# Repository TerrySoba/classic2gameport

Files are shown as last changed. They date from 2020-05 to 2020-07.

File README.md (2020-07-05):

Classic2Gameport
================

About
-----
Classic2Gameport is an adapter that allows to connect up to two [Nintendo Wii Classic Controllers](https://en.wikipedia.org/wiki/Classic_Controller) to [PC Gameports](https://en.wikipedia.org/wiki/Game_port).
The adapter acts like a Gravis Gamepad.

Supported Devices
-----------------

The following Nintendo controllers are supported:
 * Classic Controller
 * Classic Controler Pro
 * SNES Mini Controller

The PC needs to have a Gameport to use this adapter.

Adapter Modes
-------------

| Mode | Combination | Description |
|---|---|--|
| Normal Mode | SELECT + DOWN | Button B -> 1<br>Button Y -> 2<br>Button A -> 3<br>Button X -> 4 |
| Two Player Mode | (connect two controllers) | Button B1 -> 1<br>Button Y1 -> 2<br>Button B2 -> 3<br>Button Y2 -> 4<br>
| Jump'n'Run Mode | SELECT + UP | Button Y -> 1<br>Button A -> 2<br>Button B -> Up |

Building Instructions
---------------------

Here are some images of the assembled adapter:

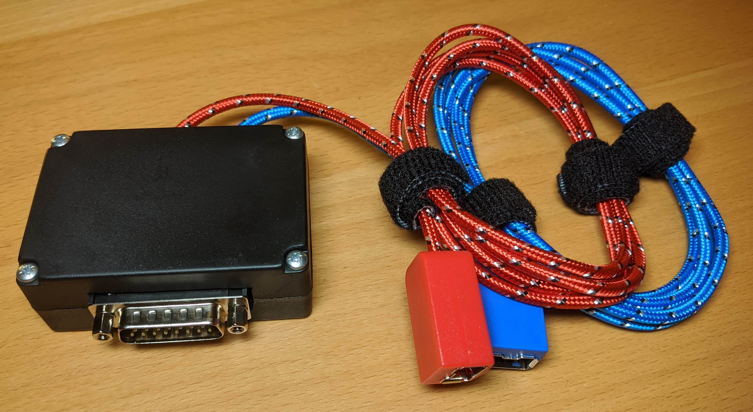
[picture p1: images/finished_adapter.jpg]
pcb v4 front The finished adapter

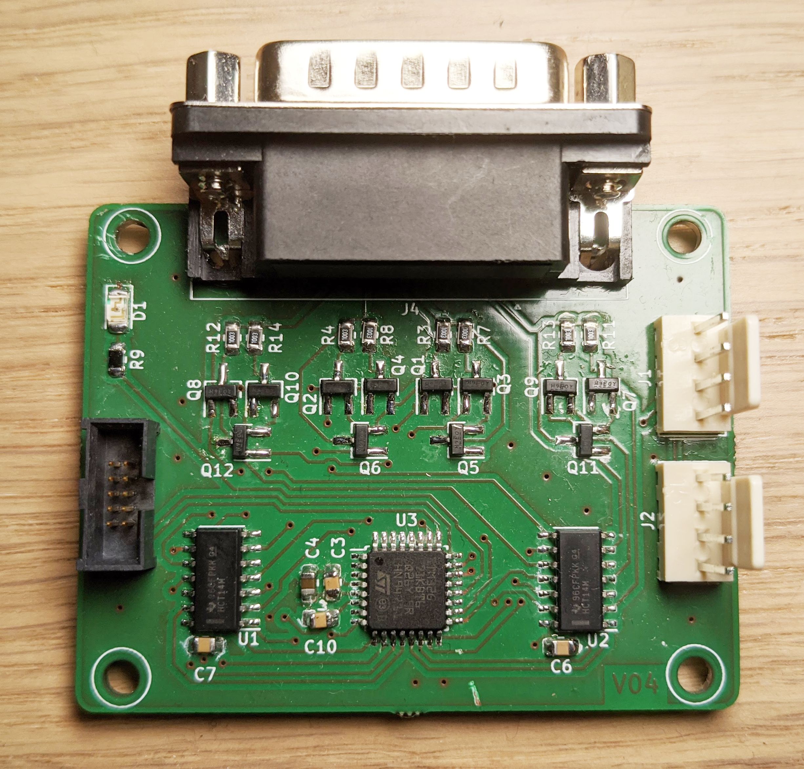
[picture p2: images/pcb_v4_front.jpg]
pcb v4 front PCB Version 4 Front

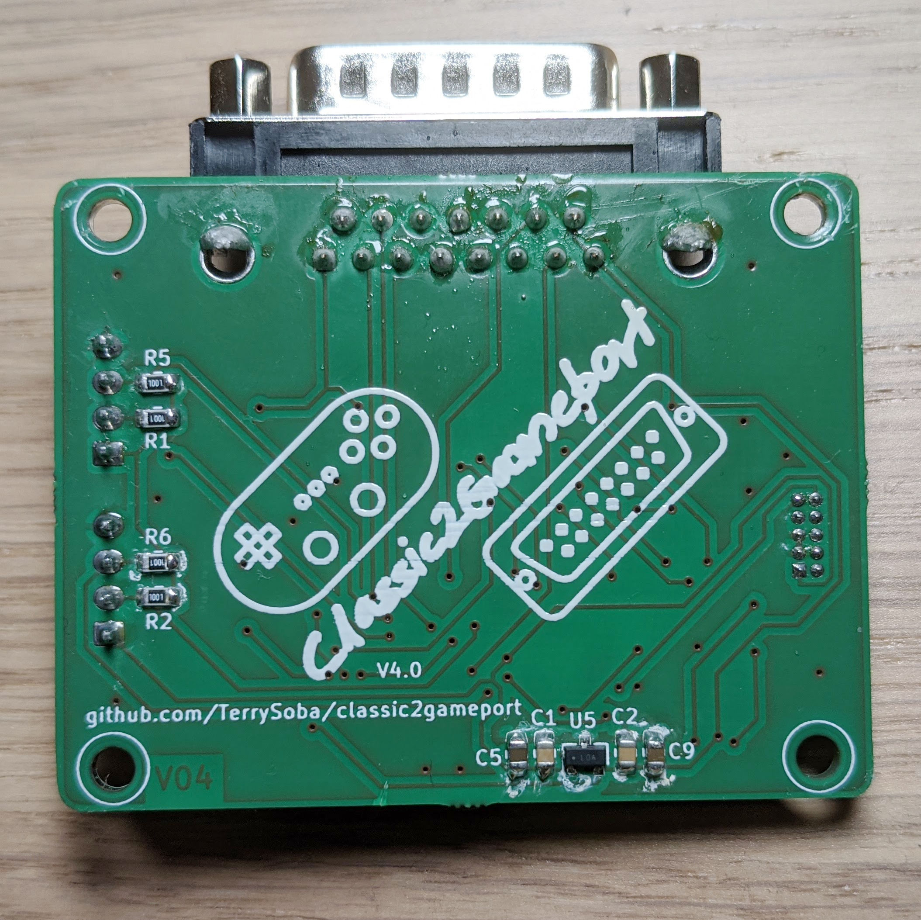
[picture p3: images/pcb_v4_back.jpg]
pcb v4 back PCB Version 4 Back


The Kicad files of the PCB can be found in the pcb directory of the repository.

The firmware for the ST STM32G071KxT microcontroller can be found in the firmware directory.

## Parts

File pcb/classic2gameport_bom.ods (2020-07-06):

Id | Designator | Package | Quantity | Designation | Supplier and ref | Digikey
1 | REF** | G026 | 1 | G026 | Reichelt: GEH KS 28
2 | U3 | LQFP-32_7x7mm_P0.8mm | 1 | STM32G071KxT | Farnell: 2980897 | 497-18355-ND
3 | C10,C7,C6,C3,C2,C1 | C_0805_2012Metric_Pad1.15x1.40mm_HandSolder | 6 | 100nF | Farnell: 2320839 | 399-8000-1-ND
4 | C9,C5 | C_0805_2012Metric_Pad1.15x1.40mm_HandSolder | 2 | 4.7µF | Farnell: 2906811 | 399-C0805C475K3RACAUTOCT-ND
5 | U5 | SOT-23 | 1 | LM3480-3.3 | Farnell: 3122097 | LM3480IM3X-3.3/NOPBCT-ND
6 | U2,U1 | SOIC-14_3.9x8.7mm_P1.27mm | 2 | 74HC14 | Farnell: 3120226 | 296-14548-1-ND
7 | R14,R13,R12,R11,R8,R7,R4,R3 | R_0805_2012Metric_Pad1.15x1.40mm_HandSolder | 8 | 100kR | Farnell: 2447551 | 311-100KCRCT-ND
8 | R9 | R_0805_2012Metric_Pad1.15x1.40mm_HandSolder | 1 | 470R | Farnell: 2447662 | A129745CT-ND
9 | R6,R5,R2,R1 | R_0805_2012Metric_Pad1.15x1.40mm_HandSolder | 4 | 1kR | Farnell: 2447587 | 311-1.0KARCT-ND
10 | Q12,Q11,Q10,Q9,Q8,Q7,Q6,Q5,Q4,Q3,Q2,Q1 | SOT-23_Handsoldering | 12 | Q_PMOS_GSD | Farnell: 9103511 | IRLML5203TRPBFCT-ND
11 | J4 | DSUB-15_Male_Horizontal_P2.77x2.84mm_EdgePinOffset4.94mm_Housed_MountingHolesOffset7.48mm | 1 | DB15_Male | Reichelt: RND 205-00772 | 732-618015211721-ND
12 | J3 | PinHeader_2x05_P1.27mm_Vertical | 1 | Conn_02x05_Odd_Even | Farnell: 2308450 | 1175-1733-ND
13 | J2,J1 | Molex_KK-254_AE-6410-04A_1x04_P2.54mm_Vertical | 2 | Conn_01x04 | Reichelt: RND 205-00664 + Reichelt: RND 205-00696 + Reichelt: RND 205-00673 | WM4202-ND
14 | D1 | LED_1206_3216Metric | 1 | LED | Reichelt: KBT KP-3216SURC | 754-APTL3216SURCK-01CT-ND
15 | C4 | C_0805_2012Metric_Pad1.15x1.40mm_HandSolder | 1 | 1µF | Farnell: 1637035 | 399-8004-1-ND

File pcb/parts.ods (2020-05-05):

Designation | Part Name | Package | Farnell Number | Value
U3 | PCA9306D,118 | SO8 | 2820288
U2 | ATMEGA8A-PU | DIP-28 | 1748534
U1 | LM3480-3.3 | SOT-23 | 3122097
J1 |  | DSUB-15 | 1099290
Y1 |  | HC-49 | 1611761 | 16MHz
Q1..Q8 | IRLML5203TRPBF | SOT-23 | 9103511
 | LED blue | 1206 | 2846600

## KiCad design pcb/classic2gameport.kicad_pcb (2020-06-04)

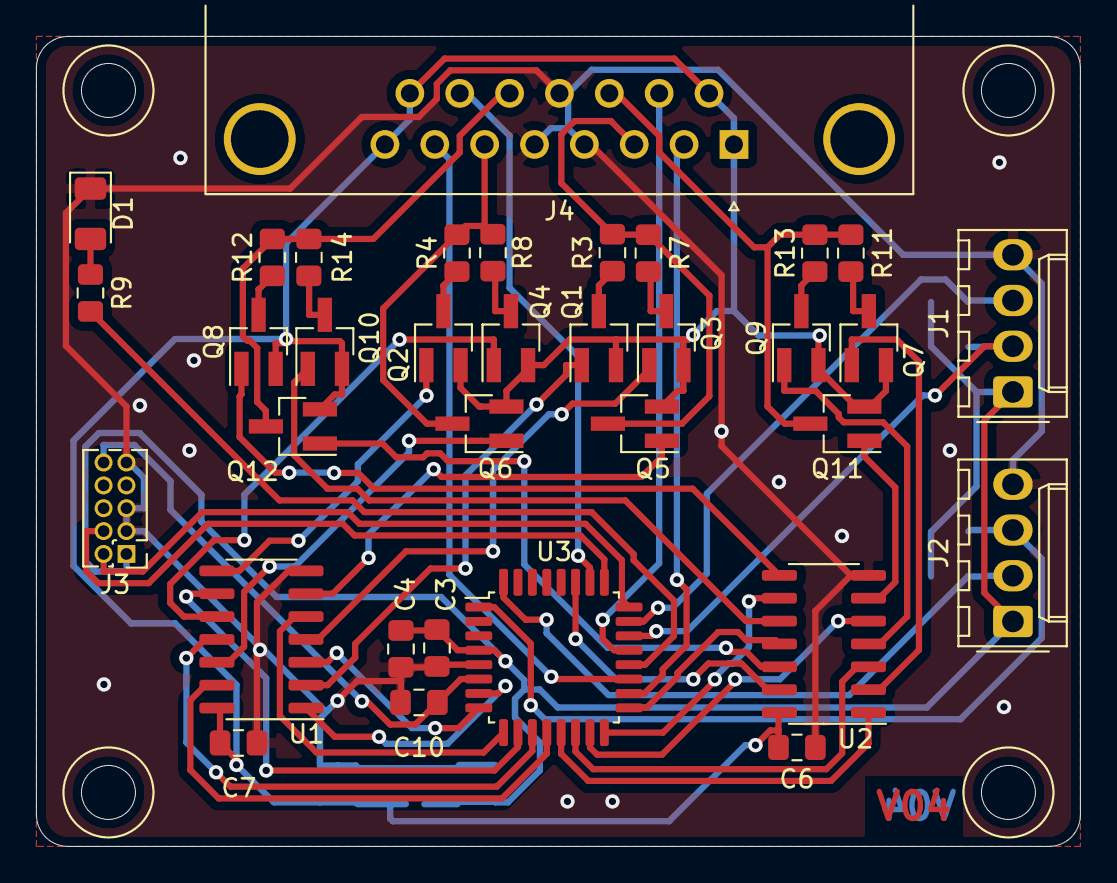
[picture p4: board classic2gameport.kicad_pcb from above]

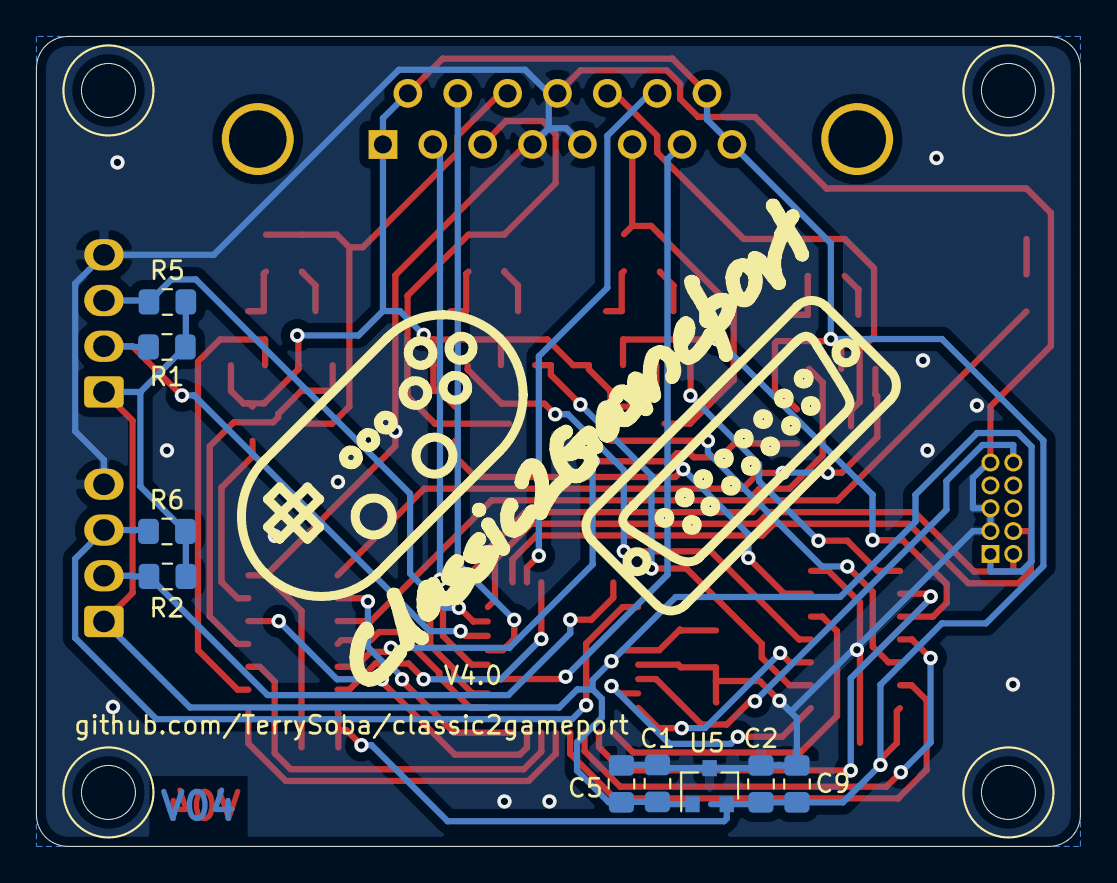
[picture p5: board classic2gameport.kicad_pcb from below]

Board: 2 copper layers, 58.0 x 45.0 mm, 43 parts (9 on the bottom side), 52 nets.

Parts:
C1, C2, C3, C6, C7, C10: 100nF; C_0805_2012Metric_Pad1.15x1.40mm_HandSolder
C4: 1µF; C_0805_2012Metric_Pad1.15x1.40mm_HandSolder
C5, C9: 4.7µF; C_0805_2012Metric_Pad1.15x1.40mm_HandSolder
D1: LED; LED_1206_3216Metric
J1, J2: Conn_01x04; Molex_KK-254_AE-6410-04A_1x04_P2.54mm_Vertical
J3: Conn_02x05_Odd_Even; PinHeader_2x05_P1.27mm_Vertical
J4: DB15_Male; DSUB-15_Male_Horizontal_P2.77x2.84mm_EdgePinOffset4.94mm_Ho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
Q1, Q2, Q3, Q4, Q5, Q6, Q7, Q8, Q9, Q10, Q11, Q12: Q_PMOS_GSD; SOT-23_Handsoldering
R1, R2, R5, R6: 1kR; R_0805_2012Metric_Pad1.15x1.40mm_HandSolder
R3, R4, R7, R8, R11, R12, R13, R14: 100kR; R_0805_2012Metric_Pad1.15x1.40mm_HandSolder
R9: 470R; R_0805_2012Metric_Pad1.15x1.40mm_HandSolder
U1, U2: 74HC14; SOIC-14_3.9x8.7mm_P1.27mm
U3: STM32G071KxT; LQFP-32_7x7mm_P0.8mm
U5: LM3480-3.3; SOT-23

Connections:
3.3V: C1.1, C3.1, C4.1, C5.1, J1.1, J2.1, J3.1, R1.1, R2.1, R5.1, R6.1, U3.4, U5.1
5V: C2.1, C6.1, C7.1, C9.1, J4.1, J4.8, J4.9, J4.15, Q1.2, Q2.2, Q3.2, Q4.2, Q5.2, Q6.2, Q7.2, Q8.2, Q9.2, Q10.2, Q11.2, Q12.2, U1.14, U2.14, U5.2
BUTTON1: J4.2, U3.18
BUTTON2: J4.7, U3.19
BUTTON3: J4.10, U3.21
BUTTON4: J4.14, U3.26
GND: C1.2, C2.2, C3.2, C4.2, C5.2, C6.2, C7.2, C9.2, C10.2, D1.1, J1.4, J2.4, J3.3, J3.5, J3.9, J4.4, J4.5, J4.12, U1.7, U2.7, U3.5, U5.3
JS1_X1: U1.1, U3.7
JS1_X2: U1.3, U3.8
JS1_X3: U1.5, U3.9
JS1_X_AXIS: J4.3, Q5.3, R3.2, R7.2
JS1_Y1: U1.9, U3.10
JS1_Y2: U1.11, U3.11
JS1_Y3: U1.13, U3.12
JS1_Y_AXIS: J4.6, Q6.3, R4.2, R8.2
JS2_X1: U2.1, U3.13
JS2_X2: U2.3, U3.14
JS2_X3: U2.5, U3.15
JS2_X_AXIS: J4.11, Q11.3, R11.2, R13.2
JS2_Y1: U2.9, U3.16
JS2_Y2: U2.11, U3.17
JS2_Y3: U2.13, U3.27
JS2_Y_AXIS: J4.13, Q12.3, R12.2, R14.2
NRST: C10.1, J3.10, U3.6
unnamed: D1.2, R9.2
unnamed: Q1.1, U1.2
unnamed: Q1.3, R3.1
unnamed: Q2.1, U1.8
unnamed: Q2.3, R4.1
unnamed: Q3.1, U1.4
unnamed: Q3.3, R7.1
unnamed: Q4.1, U1.10
unnamed: Q4.3, R8.1
unnamed: Q5.1, U1.6
unnamed: Q6.1, U1.12
unnamed: Q7.1, U2.2
unnamed: Q7.3, R11.1
unnamed: Q8.1, U2.8
unnamed: Q8.3, R12.1
unnamed: Q9.1, U2.4
unnamed: Q9.3, R13.1
unnamed: Q10.1, U2.10
unnamed: Q10.3, R14.1
unnamed: Q11.1, U2.6
unnamed: Q12.1, U2.12
unnamed: R9.1, U3.20
SCL: J2.2, R2.2, U3.32
SCL2: J1.2, R1.2, U3.22
SDA: J2.3, R6.2, U3.1
SDA2: J1.3, R5.2, U3.23
SWCLK: J3.4, U3.25
SWDIO: J3.2, U3.24

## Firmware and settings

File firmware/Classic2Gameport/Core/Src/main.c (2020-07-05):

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

/* Includes ------------------------------------------------------------------*/
#include "main.h"

/* USER CODE BEGIN Includes */
#include "classic_controller.h"
#include "gameport.h"
#include "button_mapper.h"
/* USER CODE END Includes */

I2C_HandleTypeDef hi2c1;
I2C_HandleTypeDef hi2c2;

void SystemClock_Config(void);
static void MX_GPIO_Init(void);
static void MX_I2C2_Init(void);
static void MX_I2C1_Init(void);
/* USER CODE BEGIN 0 */

ButtonMap buttonMapPort1[] =
{
    {MAP_TYPE_AXIS, true, 0, 0,                       AXIS_X2, POSITION_DISCONNECTED, 0},
    {MAP_TYPE_AXIS, true, 0, 0,                       AXIS_Y2, POSITION_DISCONNECTED, 0},
    {MAP_TYPE_AXIS, false, 1 << CLASSIC_BTN_left,  0, AXIS_X1, POSITION_MIN, 0},
    {MAP_TYPE_AXIS, false, 1 << CLASSIC_BTN_right, 0, AXIS_X1, POSITION_MAX, 0},
    {MAP_TYPE_AXIS, false, 1 << CLASSIC_BTN_up,    0, AXIS_Y1, POSITION_MIN, 0},
    {MAP_TYPE_AXIS, false, 1 << CLASSIC_BTN_down,  0, AXIS_Y1, POSITION_MAX, 0},
    {MAP_TYPE_BUTTON, false, 1 << CLASSIC_BTN_b,     0, 0, 0,                0},
    {MAP_TYPE_BUTTON, false, 1 << CLASSIC_BTN_y,     0, 0, 0,                1},
	{MAP_TYPE_BUTTON, false, 1 << CLASSIC_BTN_select,0, 0, 0,                1},
    {MAP_TYPE_BUTTON, false, 1 << CLASSIC_BTN_a,     0, 0, 0,                2},
    {MAP_TYPE_BUTTON, false, 1 << CLASSIC_BTN_x,     0, 0, 0,                3},
	{MAP_TYPE_BUTTON, false, 1 << CLASSIC_BTN_start, 0, 0, 0,                3},
    {MAP_TYPE_END,    false, 0                 ,     0, 0, 0,                0},
};

ButtonMap buttonMapPort1Jnr[] =
{
    {MAP_TYPE_AXIS, true, 0, 0,                       AXIS_X2, POSITION_DISCONNECTED, 0},
    {MAP_TYPE_AXIS, true, 0, 0,                       AXIS_Y2, POSITION_DISCONNECTED, 0},
    {MAP_TYPE_AXIS, false, 1 << CLASSIC_BTN_left,  0, AXIS_X1, POSITION_MIN, 0},
    {MAP_TYPE_AXIS, false, 1 << CLASSIC_BTN_right, 0, AXIS_X1, POSITION_MAX, 0},
    {MAP_TYPE_AXIS, false, 1 << CLASSIC_BTN_up,    0, AXIS_Y1, POSITION_MIN, 0},
    {MAP_TYPE_AXIS, false, 1 << CLASSIC_BTN_b,     0, AXIS_Y1, POSITION_MIN, 0}, // b is mapped to up
    {MAP_TYPE_AXIS, false, 1 << CLASSIC_BTN_down,  0, AXIS_Y1, POSITION_MAX, 0},
    {MAP_TYPE_BUTTON, false, 1 << CLASSIC_BTN_y,     0, 0, 0,                0},
    {MAP_TYPE_BUTTON, false, 1 << CLASSIC_BTN_a,     0, 0, 0,                1},
    {MAP_TYPE_END,    false, 0                 ,     0, 0, 0,                0},
};

ButtonMap buttonMapPort2[] =
{
    {MAP_TYPE_AXIS, true, 0, 0,                       AXIS_X2, POSITION_DISCONNECTED, 0},
    {MAP_TYPE_AXIS, true, 0, 0,                       AXIS_Y2, POSITION_DISCONNECTED, 0},
    {MAP_TYPE_AXIS, false, 0, 1 << CLASSIC_BTN_left,  AXIS_X1, POSITION_MIN, 0},
    {MAP_TYPE_AXIS, false, 0, 1 << CLASSIC_BTN_right, AXIS_X1, POSITION_MAX, 0},
    {MAP_TYPE_AXIS, false, 0, 1 << CLASSIC_BTN_up,    AXIS_Y1, POSITION_MIN, 0},
    {MAP_TYPE_AXIS, false, 0, 1 << CLASSIC_BTN_down,  AXIS_Y1, POSITION_MAX, 0},
    {MAP_TYPE_BUTTON, false, 0, 1 << CLASSIC_BTN_b,     0, 0,                0},
    {MAP_TYPE_BUTTON, false, 0, 1 << CLASSIC_BTN_y,     0, 0,                1},
	{MAP_TYPE_BUTTON, false, 0, 1 << CLASSIC_BTN_select,0, 0,                1},
    {MAP_TYPE_BUTTON, false, 0, 1 << CLASSIC_BTN_a,     0, 0,                2},
    {MAP_TYPE_BUTTON, false, 0, 1 << CLASSIC_BTN_x,     0, 0,                3},
	{MAP_TYPE_BUTTON, false, 0, 1 << CLASSIC_BTN_start, 0, 0,                3},
    {MAP_TYPE_END,  false, 0,                  0,       0, 0,                0},
};

ButtonMap buttonMapPort2Jnr[] =
{
    {MAP_TYPE_AXIS, true, 0, 0,                       AXIS_X2, POSITION_DISCONNECTED, 0},
    {MAP_TYPE_AXIS, true, 0, 0,                       AXIS_Y2, POSITION_DISCONNECTED, 0},
    {MAP_TYPE_AXIS, false, 0, 1 << CLASSIC_BTN_left,  AXIS_X1, POSITION_MIN, 0},
    {MAP_TYPE_AXIS, false, 0, 1 << CLASSIC_BTN_right, AXIS_X1, POSITION_MAX, 0},
    {MAP_TYPE_AXIS, false, 0, 1 << CLASSIC_BTN_up,    AXIS_Y1, POSITION_MIN, 0},
    {MAP_TYPE_AXIS, false, 0, 1 << CLASSIC_BTN_b,     AXIS_Y1, POSITION_MIN, 0}, // b is mapped to up
    {MAP_TYPE_AXIS, false, 0, 1 << CLASSIC_BTN_down,  AXIS_Y1, POSITION_MAX, 0},
    {MAP_TYPE_BUTTON, false, 0, 1 << CLASSIC_BTN_y,     0, 0,                0},
    {MAP_TYPE_BUTTON, false, 0, 1 << CLASSIC_BTN_a,     0, 0,                1},
    {MAP_TYPE_END,  false, 0,                  0,       0, 0,                0},
};

ButtonMap buttonMapBoth[] =
{
    {MAP_TYPE_AXIS, false, 1 << CLASSIC_BTN_left,  0, AXIS_X1, POSITION_MIN, 0},
    {MAP_TYPE_AXIS, false, 1 << CLASSIC_BTN_right, 0, AXIS_X1, POSITION_MAX, 0},
    {MAP_TYPE_AXIS, false, 1 << CLASSIC_BTN_up,    0, AXIS_Y1, POSITION_MIN, 0},
    {MAP_TYPE_AXIS, false, 1 << CLASSIC_BTN_down,  0, AXIS_Y1, POSITION_MAX, 0},
    {MAP_TYPE_AXIS, false, 0, 1 << CLASSIC_BTN_left,  AXIS_X2, POSITION_MIN, 0},
    {MAP_TYPE_AXIS, false, 0, 1 << CLASSIC_BTN_right, AXIS_X2, POSITION_MAX, 0},
    {MAP_TYPE_AXIS, false, 0, 1 << CLASSIC_BTN_up,    AXIS_Y2, POSITION_MIN, 0},
    {MAP_TYPE_AXIS, false, 0, 1 << CLASSIC_BTN_down,  AXIS_Y2, POSITION_MAX, 0},
    {MAP_TYPE_BUTTON, false, 1 << CLASSIC_BTN_b,    0,  0, 0,                0},
    {MAP_TYPE_BUTTON, false, 1 << CLASSIC_BTN_y,    0,  0, 0,                1},
    {MAP_TYPE_BUTTON, false, 0, 1 << CLASSIC_BTN_b,     0, 0,                2},
    {MAP_TYPE_BUTTON, false, 0, 1 << CLASSIC_BTN_y,     0, 0,                3},
    {MAP_TYPE_END, false, 0,                  0,        0, 0,                0},
};

ButtonMap buttonMapBothJnr[] =
{
    {MAP_TYPE_AXIS, false, 1 << CLASSIC_BTN_left,  0, AXIS_X1, POSITION_MIN, 0},
    {MAP_TYPE_AXIS, false, 1 << CLASSIC_BTN_right, 0, AXIS_X1, POSITION_MAX, 0},
    {MAP_TYPE_AXIS, false, 1 << CLASSIC_BTN_up,    0, AXIS_Y1, POSITION_MIN, 0},
    {MAP_TYPE_AXIS, false, 1 << CLASSIC_BTN_b,     0, AXIS_Y1, POSITION_MIN, 0}, // b is also mapped to up
    {MAP_TYPE_AXIS, false, 1 << CLASSIC_BTN_down,  0, AXIS_Y1, POSITION_MAX, 0},
    {MAP_TYPE_AXIS, false, 0, 1 << CLASSIC_BTN_left,  AXIS_X2, POSITION_MIN, 0},
    {MAP_TYPE_AXIS, false, 0, 1 << CLASSIC_BTN_right, AXIS_X2, POSITION_MAX, 0},
    {MAP_TYPE_AXIS, false, 0, 1 << CLASSIC_BTN_up,    AXIS_Y2, POSITION_MIN, 0},
    {MAP_TYPE_AXIS, false, 0, 1 << CLASSIC_BTN_b,     AXIS_Y2, POSITION_MIN, 0}, // b is also mapped to up
    {MAP_TYPE_AXIS, false, 0, 1 << CLASSIC_BTN_down,  AXIS_Y2, POSITION_MAX, 0},
    {MAP_TYPE_BUTTON, false, 1 << CLASSIC_BTN_y,    0,  0, 0,                0},
    {MAP_TYPE_BUTTON, false, 1 << CLASSIC_BTN_a,    0,  0, 0,                1},
    {MAP_TYPE_BUTTON, false, 0, 1 << CLASSIC_BTN_y,     0, 0,                2},
    {MAP_TYPE_BUTTON, false, 0, 1 << CLASSIC_BTN_a,     0, 0,                3},
    {MAP_TYPE_END, false, 0,                  0,        0, 0,                0},
};

static const uint16_t normalModeButtons = ~(1 << CLASSIC_BTN_select | 1 << CLASSIC_BTN_down);
static const uint16_t jumpAndRunModeButtons = ~(1 << CLASSIC_BTN_select | 1 << CLASSIC_BTN_up);

bool jumpAndRunMode = false;

/* USER CODE END 0 */

/**
  * @brief  The application entry point.
  * @retval int
  */
int main(void)
{
  /* MCU Configuration--------------------------------------------------------*/

  /* Reset of all peripherals, Initializes the Flash interface and the Systick. */
  HAL_Init();

  /* Configure the system clock */
  SystemClock_Config();

  /* Initialize all configured peripherals */
  MX_GPIO_Init();
  MX_I2C2_Init();
  MX_I2C1_Init();
  /* USER CODE BEGIN 2 */
soft_reset:

  HAL_Delay(100);
  initializeClassicController(&hi2c1);
  initializeClassicController(&hi2c2);
  HAL_Delay(100);

  /* USER CODE END 2 */

  /* Infinite loop */
  /* USER CODE BEGIN WHILE */

  uint16_t classicControllerButtons1 = 0;
  uint16_t classicControllerButtons2 = 0;

  while (1)
  {
    bool pad1Ready = readClassicControllerData(&hi2c1, &classicControllerButtons1);
    bool pad2Ready = readClassicControllerData(&hi2c2, &classicControllerButtons2);


    if (!pad1Ready && !pad2Ready)
    {
      goto soft_reset;
    }

    if (jumpAndRunModeButtons == classicControllerButtons1 || jumpAndRunModeButtons == classicControllerButtons2)
    {
      jumpAndRunMode = true;
    }

    if (normalModeButtons == classicControllerButtons1 || normalModeButtons == classicControllerButtons2)
    {
      jumpAndRunMode = false;
    }



    ButtonMap* map;


    if (pad1Ready && pad2Ready)
    {
      map = jumpAndRunMode?buttonMapBothJnr:buttonMapBoth;
    }
    else if (pad1Ready)
    {
      map = jumpAndRunMode?buttonMapPort1Jnr:buttonMapPort1;
    }
    else
    {
      map = jumpAndRunMode?buttonMapPort2Jnr:buttonMapPort2;
    }
  

    GameportState gameportState = mapButtons(classicControllerButtons1, classicControllerButtons2, map);
    setGameport(&gameportState);

    /* USER CODE END WHILE */

    /* USER CODE BEGIN 3 */
  }
  /* USER CODE END 3 */
}

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


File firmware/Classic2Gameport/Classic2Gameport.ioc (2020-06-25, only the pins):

Mcu.UserName=STM32G071KBTx
PA0.Signal=GPIO_Output
PA1.Signal=GPIO_Output
PA10.Signal=GPIO_Input
PA15.Signal=GPIO_Input
PA2.Signal=GPIO_Output
PA3.Signal=GPIO_Output
PA4.Signal=GPIO_Output
PA5.Signal=GPIO_Output
PA6.Signal=GPIO_Output
PA7.Signal=GPIO_Output
PA8.Signal=GPIO_Input
PA9.Signal=GPIO_Input
PB0.Signal=GPIO_Output
PB1.Signal=GPIO_Output
PB2.Signal=GPIO_Output
PB3.Signal=GPIO_Output
PB8.Signal=I2C1_SCL
PB9.Signal=I2C1_SDA
PC6.Signal=GPIO_Output

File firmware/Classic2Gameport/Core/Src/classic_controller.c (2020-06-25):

#include "classic_controller.h"

#include "my_debug.h"


#define CLASSIC_CONTROLLER_ADDR 0x52 /* address of classic controller and nunchuck */

bool initializeClassicController(I2C_HandleTypeDef *i2c) {
    unsigned char initData[2] = { 0x40, 0x00 };
    HAL_StatusTypeDef ret = HAL_I2C_Master_Transmit(i2c, CLASSIC_CONTROLLER_ADDR << 1,
            initData, 2, HAL_MAX_DELAY);
    if (ret != HAL_OK) {
        debugPrintf("ret==%d", ret);
        return false;
    }

    return true;
}


bool readClassicControllerData(I2C_HandleTypeDef* i2c, uint16_t* buttonData) {
    unsigned char zeroData[1] = { 0x00 };
    HAL_StatusTypeDef ret = HAL_I2C_Master_Transmit(i2c, CLASSIC_CONTROLLER_ADDR << 1, zeroData, 1,
            HAL_MAX_DELAY);
    if (ret != HAL_OK) {
        debugPrintf("ret2==%d", ret);
        return false;
    }

    // HAL_Delay(2);
    HAL_Delay(1);

    // now receive controller data
    uint8_t buf[6];
    ret = HAL_I2C_Master_Receive(i2c, CLASSIC_CONTROLLER_ADDR << 1, buf, 6,
            HAL_MAX_DELAY);
    if (ret != HAL_OK) {
        debugPrintf("ret3==%d", ret);
        return false;
    }

    // now decrypt data
    for (uint8_t i = 0; i < 6; ++i) {
        buf[i] = (buf[i] ^ 0x17) + 0x17; // decrypt data
    }


    *buttonData = buf[4] | (buf[5] << 8);

    return true;
}

bool isButtonPressed(ClassicButtons button, uint16_t buttons)
{
    return !(buttons & (1 << button));
}

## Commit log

2020-05-04 Initial import
    [classic2gameport.kicad_pcb, classic2gameport.sch]
2020-05-05 Add LED
    [classic2gameport.kicad_pcb, classic2gameport.sch]
2020-05-05 Add (incomplete) BOM
    [parts.ods]
2020-05-06 Slightly change layout
    [classic2gameport.kicad_pcb]
2020-05-07 Add BOM
    [classic2gameport.kicad_pcb, classic2gameport_bom.ods]
2020-05-10 Change some footprints
    [classic2gameport.kicad_pcb, classic2gameport.sch]
2020-05-12 Add gitignore
    [classic2gameport_bom.ods]
2020-05-23 Change to STM32 MCU
    [classic2gameport.kicad_pcb, classic2gameport.sch, classic2gameport_bom.ods]
2020-05-23 Redesign again
    [classic2gameport.kicad_pcb, classic2gameport.sch]
2020-06-01 Change firmware to STM32
2020-06-01 Fix PCB
    [classic2gameport.sch]
2020-06-04 Version 4.0 of PCB
    [classic2gameport.kicad_pcb, classic2gameport.sch]
2020-06-04 Fix silkscreen
    [classic2gameport.kicad_pcb]
2020-06-25 Intermediate state
    [classic2gameport_bom.ods]
2020-06-25 Change MCU to STM32G071KB
2020-07-02 Allow mapping of buttons
2020-07-04 Change order of ButtonMap
2020-07-06 Add digikey numbers to BOM
    [classic2gameport_bom.ods]

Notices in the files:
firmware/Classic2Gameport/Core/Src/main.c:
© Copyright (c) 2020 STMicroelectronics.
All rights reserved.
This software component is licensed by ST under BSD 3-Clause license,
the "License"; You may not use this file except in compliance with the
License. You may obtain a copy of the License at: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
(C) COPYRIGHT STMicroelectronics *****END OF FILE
